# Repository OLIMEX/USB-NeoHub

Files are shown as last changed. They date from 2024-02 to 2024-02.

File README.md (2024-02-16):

# USB-NeoHub
USB 1.1 and USB 2.0 compliant hub compatible with RP2040 PICO USB and TinyUSB allowing keyboard, USB Flash and other peripherals to be used together

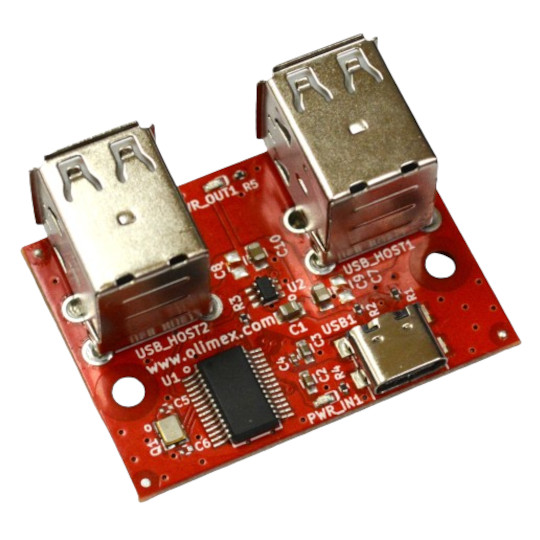
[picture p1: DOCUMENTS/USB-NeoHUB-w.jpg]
USB-NeoHUB-w


## Features

* USB 1.1 and USB 2.0 compatible
* USB-C input
* USB-A x4 output
* Input power status LED
* Output power status LED
* current protection
* Industrial grade temperature range: -40+85℃
* Dimensions 46x34 mm

## Licenses

* Hardware is released under CERN Open Hardware Licence Version 2 - Strongly Reciprocal, all silkscreen credits to Olimex should remain;
* Software is released under GPL3 Licensee
* Documentation is released under CC BY-SA 4.0

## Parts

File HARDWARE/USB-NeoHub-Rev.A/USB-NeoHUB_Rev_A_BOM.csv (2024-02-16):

Id | Designator | Footprint | Quantity | Designation | Supplier and ref
1 | U2 | SOT23-6 | 1 | CH217K(SOT23-6L)
2 | MH2,MH1 | Mounting_Hole_Drill-3.3mm_Clerance-7mm | 2 | Mounting_Hole_NPTH
3 | R5,R1,R2,R4 | R_0402_5MIL_DWS | 4 | 5.1k/1%/R0402
4 | R3 | R_0402_5MIL_DWS | 1 | 30.1k/1%/R0402
5 | C4 | C_0402_5MIL_DWS | 1 | 100nF/10V/10%/X7R/C0402
6 | FID4,FID3 | Fiducial1x3_Paste | 2 | Fiducial
7 | USB_HOST1,USB_HOST2 | USB_TWO_LEVEL | 2 | USBB1-FRWH-4A(USB-Ax2)
8 | U1 | SSOP28 | 1 | CH334S(SSOP-28)
9 | USB1 | USB2.0_TYPE-C(A40-00119-A52-12)_Paste | 1 | USB-C-16P-F(A40-00119-A52-12)
10 | FID2,FID1 | Fiducial1x3 | 2 | Fiducial
11 | PWR_OUT1,PWR_IN1 | LED_0603_KA | 2 | LED/GREEN/0603
12 | C7,C8 | C_0805_5MIL_DWS | 2 | NA(47uF/6.3V/20%/X5R/C0805)
13 | C3 | C_0603_5MIL_DWS | 1 | 10uF/6.3V/20%/X5R/C0603
14 | C5,C6 | C_0402_5MIL_DWS | 2 | NA(27pF/50V/5%/C0G/C0402)
15 | Q1 | TSX-3.2x2.5mm_GND(3) | 1 | Q12MHz/20pF/10ppm/4P/3.2x2.5mm
16 | C1,C9,C10 | C_0805_5MIL_DWS | 3 | 47uF/6.3V/20%/X5R/C0805
17 | C2 | C_0603_5MIL_DWS | 1 | 1uF/10V/20%/X5R/C0603
18 | Sign_RoHS_1 | Sign_RoHS_1 | 1 | Sign_RoHS_1
19 | Sign_RecycleBin_1 | Sign_RecycleBin_1 | 1 | Sign_RecycleBin_1
20 | Logo_OLIMEX_TB | Logo_OLIMEX_TB | 1 | Logo_OLIMEX_TB
21 | Sign_CE | CE_Sign | 1 | CE_Sign
22 | Sign_Antistatic | Sign_Antistatic | 1 | Sign_Antistatic
23 | Sign_PB-Free | Sign_PB-Free | 1 | Sign_PB-Free

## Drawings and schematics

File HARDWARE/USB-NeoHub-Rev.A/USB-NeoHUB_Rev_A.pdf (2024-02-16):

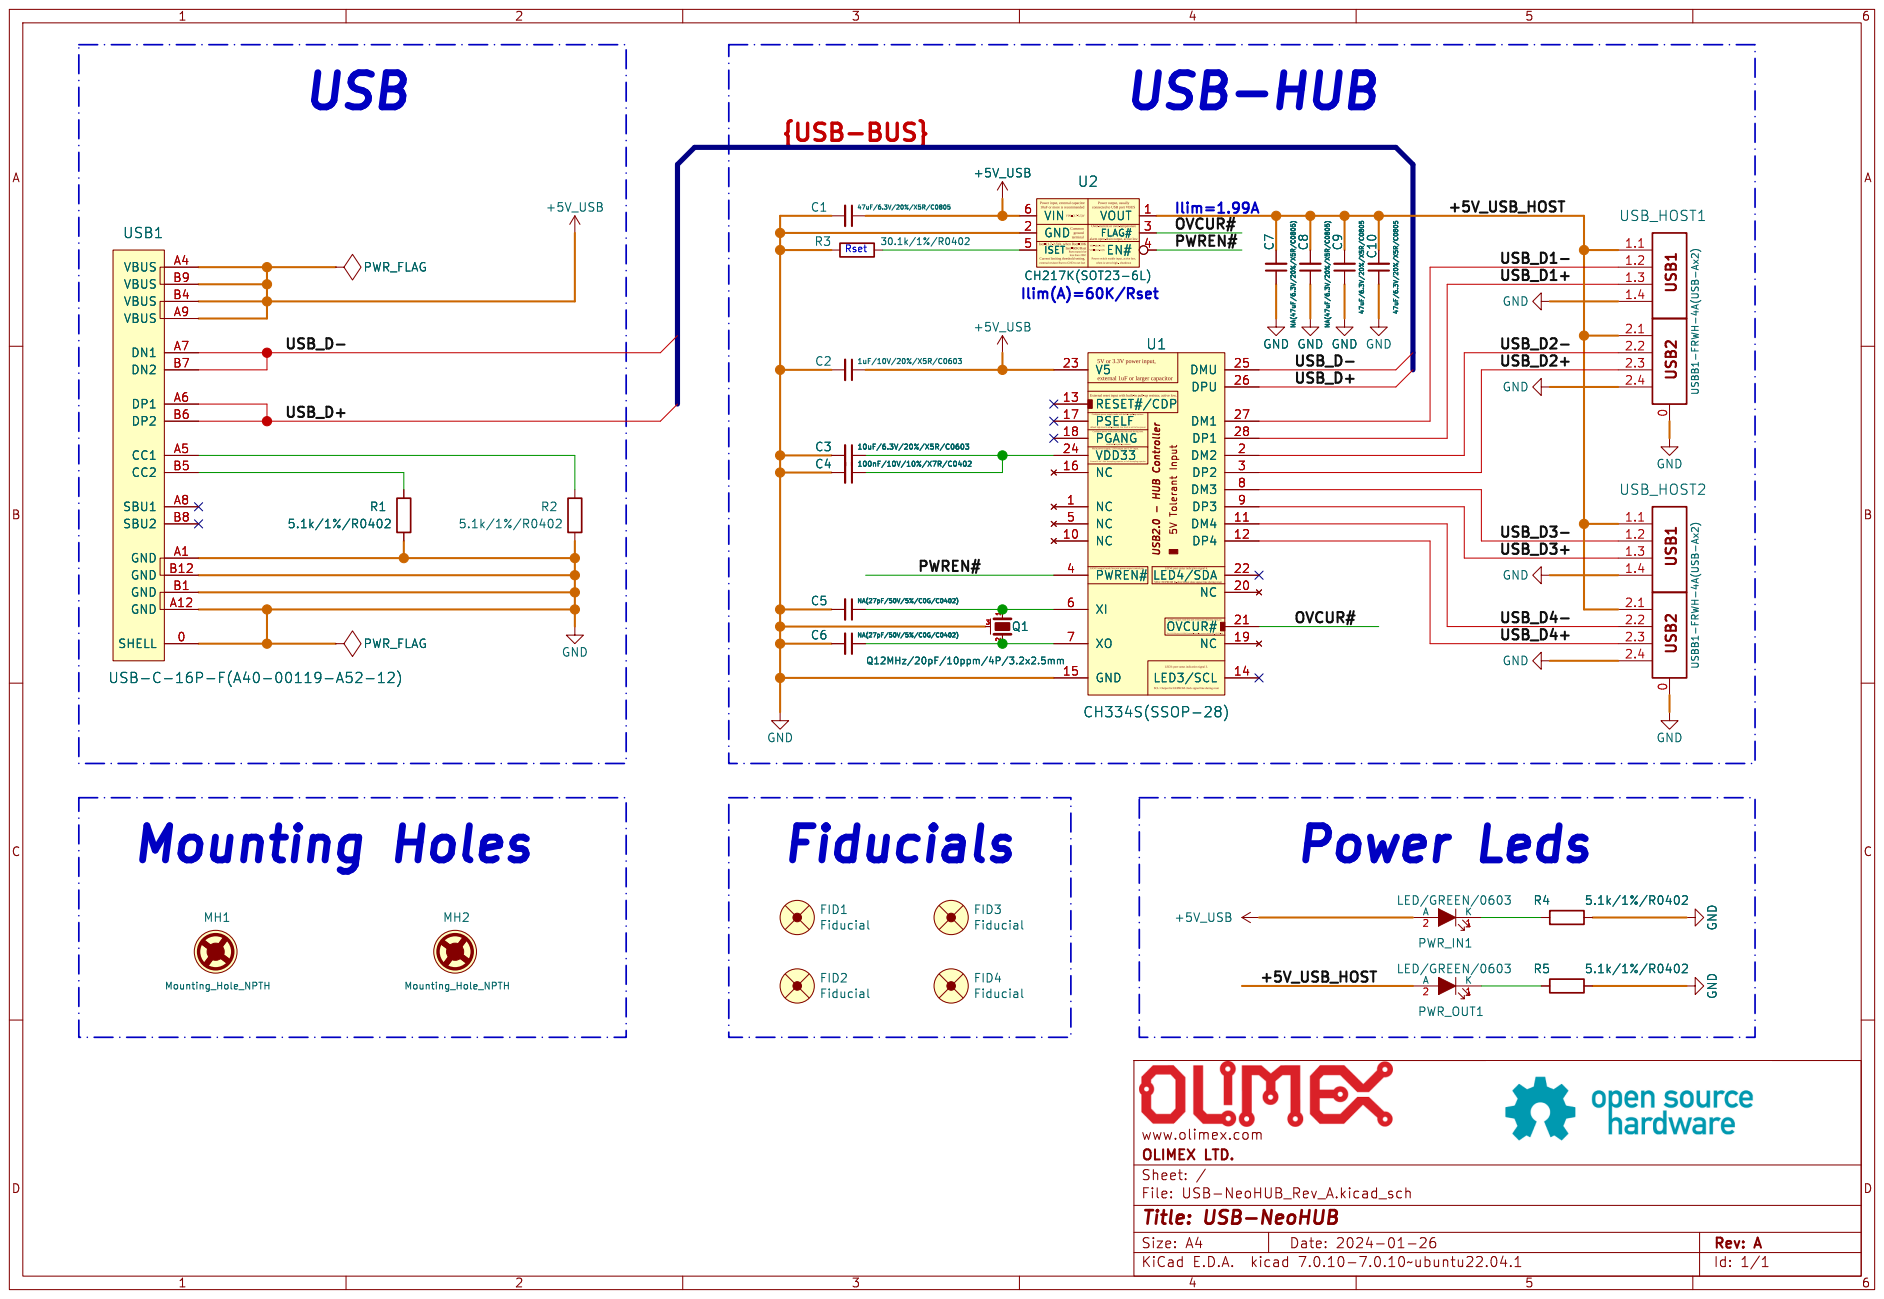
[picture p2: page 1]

lessthan22K! 10uFor moreis recommended | Over-currentor over-temperature Powerinput,externalcapacitor Poweroutput,usually Powerswitchenableinput,activelow, Rsetmustn'tbe VIL=(0.0-0.7)V VIN=(2.7-5.5)V whenis setto high - shutdown VOUT | 1 GND 2

terminal | connectedto USBportVBUS Currentlimiting thresholdsetting, externalresistorRsetto GND to setIset ground alarmopen-drainoutput,activelow Common VIH=(1.8-5.0)V

2.4 USB_HOST1USBB1-FRWH-4A(USB-Ax2) GND GND GND

Iset=(1.7-2.3)A,whenRset=30K Iset=60K/Rset

Configurepowerovercurrentprotectionmodeduringreset Configurepowersupplymodewith built-in pull-up resistor: defaulthigh level is self-powered,low level is setfor buspower External0.1uF+10uFdecouplingcapacitor,or 1uFdecouplingcapacitor external1uFor largercapacitor Externalresetinput with built-in pull-up resistor,activelow.

SCL:Outputfor EEPROMclock signalline duringreset SDA: EEPROMbi-directionaldatasignalline duringreset TheOVCUR#pin of CH334/5hasbuilt-in pull-up resistor(defaultOC_LEVEL=0).

Id: 1/1 Title: USB-NeoHUB

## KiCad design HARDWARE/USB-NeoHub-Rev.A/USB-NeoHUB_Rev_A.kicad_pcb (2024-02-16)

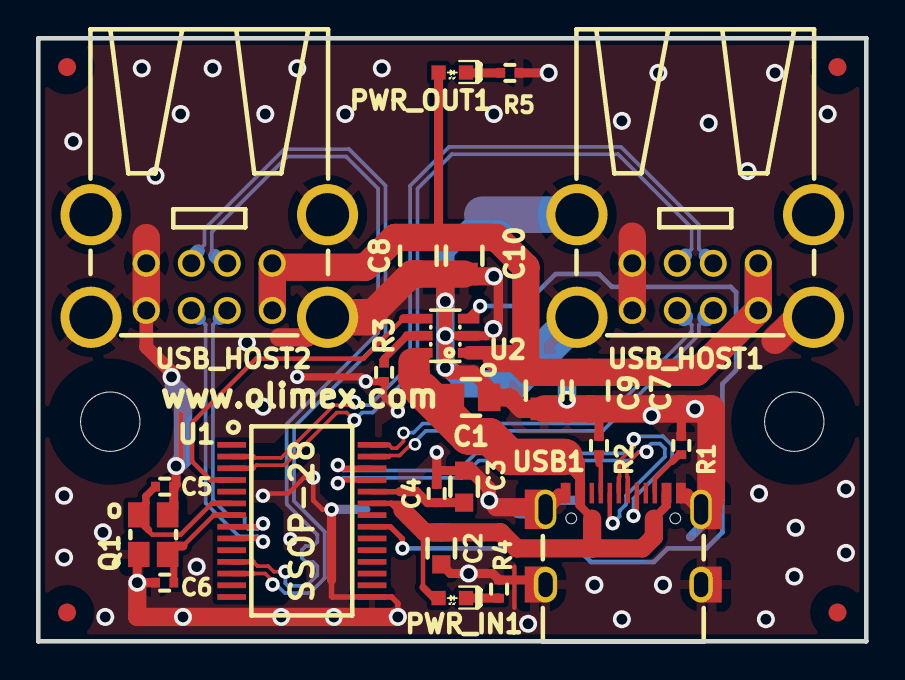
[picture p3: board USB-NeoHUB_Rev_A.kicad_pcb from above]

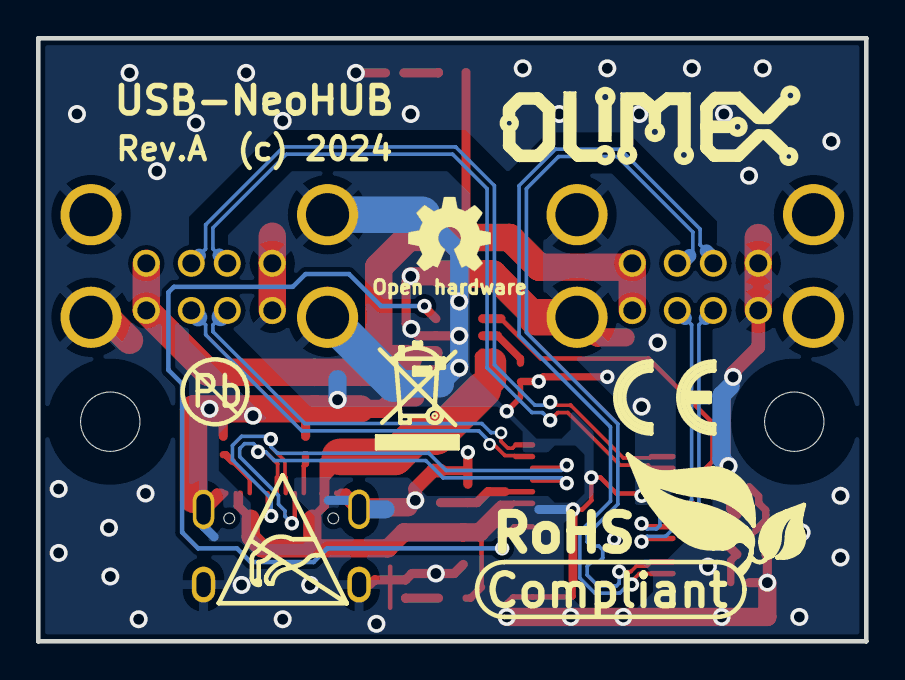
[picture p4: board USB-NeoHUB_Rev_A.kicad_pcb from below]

Board: 2 copper layers, 46.0 x 33.5 mm, 36 parts (7 on the bottom side), 23 nets.

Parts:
C1, C9, C10: 47uF/6.3V/20%/X5R/C0805; C_0805_5MIL_DWS
C2: 1uF/10V/20%/X5R/C0603; C_0603_5MIL_DWS
C3: 10uF/6.3V/20%/X5R/C0603; C_0603_5MIL_DWS
C4: 100nF/10V/10%/X7R/C0402; C_0402_5MIL_DWS
C5, C6: NA(27pF/50V/5%/C0G/C0402); C_0402_5MIL_DWS
C7, C8: NA(47uF/6.3V/20%/X5R/C0805); C_0805_5MIL_DWS
FID1, FID2: Fiducial; Fiducial1x3
FID3, FID4: Fiducial; Fiducial1x3_Paste
Logo_OLIMEX_TB: Logo_OLIMEX_TB
MH1, MH2: Mounting_Hole_NPTH; Mounting_Hole_Drill-3.3mm_Clerance-7mm
PWR_IN1: LED/GREEN/0603; LED_0603_KA
PWR_OUT1: LED/GREEN/0603; LED_0603_KA
Q1: Q12MHz/20pF/10ppm/4P/3.2x2.5mm; TSX-3.2x2.5mm_GND(3)
R1, R2, R4, R5: 5.1k/1%/R0402; R_0402_5MIL_DWS
R3: 30.1k/1%/R0402; R_0402_5MIL_DWS
Sign_Antistatic: Sign_Antistatic
Sign_CE: CE_Sign
Sign_OSHW_7.3x6.0mm: Sign_OSHW_7.3x6.0mm; Sign_OSHW_7.3x6.0mmn
Sign_PB-Free: Sign_PB-Free
Sign_RecycleBin_1: Sign_RecycleBin_1
Sign_RoHS_1: Sign_RoHS_1
U1: CH334S(SSOP-28); SSOP28
U2: CH217K(SOT23-6L); SOT23-6
USB1: USB-C-16P-F(A40-00119-A52-12); USB2.0_TYPE-C(A40-00119-A52-12)_Paste
USB_HOST1, USB_HOST2: USBB1-FRWH-4A(USB-Ax2); USB_TWO_LEVEL

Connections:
+5V_USB: C1.1, C2.1, PWR_IN1.2 (A), U1.23 (V5), U2.6 (VIN), USB1.A4 (VBUS), USB1.A9 (VBUS), USB1.B4 (VBUS), USB1.B9 (VBUS)
/+5V_USB_HOST: C7.2, C8.2, C9.2, C10.2, PWR_OUT1.2 (A), U2.1 (VOUT), USB_HOST1.1.1, USB_HOST1.2.1, USB_HOST2.1.1, USB_HOST2.2.1
/OVCUR#: U1.21 (OVCUR#), U2.3 (FLAG#)
/PWREN#: U1.4 (PWREN#), U2.4 (EN#)
/USB_D1+: U1.28 (DP1), USB_HOST1.1.3
/USB_D1-: U1.27 (DM1), USB_HOST1.1.2
/USB_D2+: U1.3 (DP2), USB_HOST1.2.3
/USB_D2-: U1.2 (DM2), USB_HOST1.2.2
/USB_D3+: U1.9 (DP3), USB_HOST2.1.3
/USB_D3-: U1.8 (DM3), USB_HOST2.1.2
/USB_D4+: U1.12 (DP4), USB_HOST2.2.3
/USB_D4-: U1.11 (DM4), USB_HOST2.2.2
/USB_D+: U1.26 (DPU), USB1.A6 (DP1), USB1.B6 (DP2)
/USB_D-: U1.25 (DMU), USB1.A7 (DN1), USB1.B7 (DN2)
GND: C1.2, C2.2, C3.2, C4.2, C5.2, C6.2, C7.1, C8.1, C9.1, C10.1, Q1.3 (case), R1.1, R2.1, R3.1, R4.2, R5.2, U1.15 (GND), U2.2 (GND), USB1.0 (SHELL), USB1.A1 (GND), USB1.A12 (GND), USB1.B1 (GND), USB1.B12 (GND), USB_HOST1.0, USB_HOST1.1.4, USB_HOST1.2.4, USB_HOST2.0, USB_HOST2.1.4, USB_HOST2.2.4
unnamed: PWR_IN1.1 (K), R4.1
unnamed: PWR_OUT1.1 (K), R5.1
unnamed: C3.1, C4.1, U1.24 (VDD33)
unnamed: C5.1, Q1.1, U1.6 (XI)
unnamed: C6.1, Q1.2, U1.7 (XO)
unnamed: R3.2, U2.5 (ISET)
unnamed: R2.2, USB1.A5 (CC1)
unnamed: R1.2, USB1.B5 (CC2)

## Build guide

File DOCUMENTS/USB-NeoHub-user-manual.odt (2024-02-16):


USB-NeoHub

User Manual

Rev.1.0 February 2024 olimex.com

# What is USB-NeoHub

USB-NeoHub (https://www.olimex.com/Products/USB-Modules/USB-NeoHub/open-source-hardware) is USB hub which is both USB 1.1 and USB 2.0 compatible. This is important as Neo6502 modern retro computer uses RP2040 to interface USB keyboards and USB Flash drives.

RP2040 USB interface is USB 1.1

For some weird reason not all USB hubs on the market support this standard which leads to incompatibilities. If you attach USB keyboard to Neo6502 it works, same is if you attach directly USB Flash. But if you attach USB keyboard through USB hub there is 50:50 chance that it may or may not work.

To save the customer frustration we decided to find USB hub chip set which guaranteed works with Neo6502.

This is how USB-NeoHub (https://www.olimex.com/Products/USB-Modules/USB-NeoHub/open-source-hardware) was made.

# USB-NeoHub features:

- USB 1.1 and USB 2.0 compliant
- USB-C device input
- USB-A x4 host outputs
- works with Neo6502, PC, OLinuXino, Raspberry Pi, RP2040-PICO and RP2040-PICO W
- Industrial grade -40+85C
- Dimensions are: 46 x 34

# Order codes for USB-NeoHub:

USB-NeoHub (https://www.olimex.com/Products/USB-Modules/USB-NeoHub/open-source-hardware) industrial grade -40+85C USB hub compatible with Neo6502

USB-CABLE-A-TO-C-1M (https://www.olimex.com/Products/Components/Cables/USB-CABLE-A-TO-C-1M/) USB-C cable

# HARDWARE

## USB-NeoHub layout:

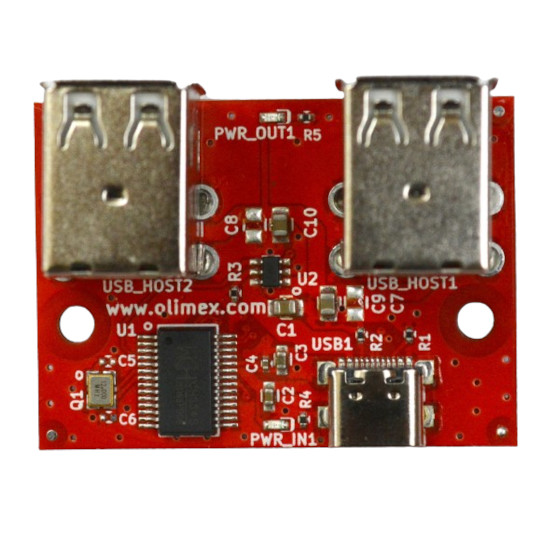
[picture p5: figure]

USB-C power indicator

USB-C device input

Dual USB-A host

USB host power indicator

Dual USB-A host

## USB-NeoHub schematics:

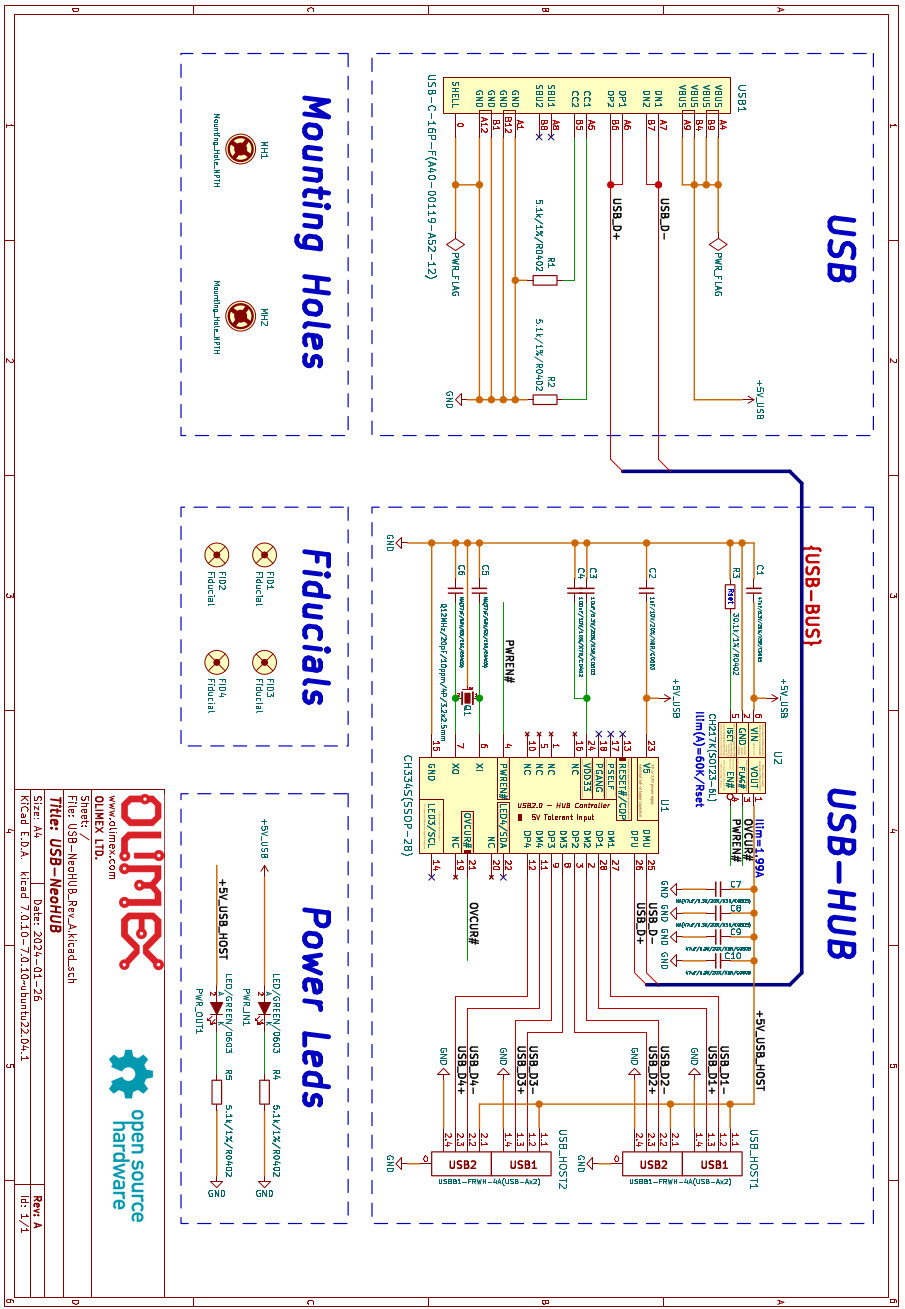
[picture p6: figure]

# Revision History

Revision 1.0 February 2024

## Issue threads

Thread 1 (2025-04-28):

power issue?

Mangerio, 2025-04-28:
Have tested the following system:
Tang Nano 20K + m0s Dock MCU and USB-NeoHub
with an Amiga 500 Keyboard driven by an Arduino Micro

It works some times and often it doesen't.
It works when the Power Out LED is on.
It works always with a wireless PC keyboard.
Does the Amiga KBD & Arduino Micro take too much power?
How is the current protection of the NeoHUB working?
What does the Power Out LED tell us exactly?

Mangerio, 2025-04-28:
The problem might be solved.
It probably was a weak powersupply.

Mangerio, 2025-04-28:
The NeoHUB might not get enough power from the m0s Dock?

Closed 2025-05-03.

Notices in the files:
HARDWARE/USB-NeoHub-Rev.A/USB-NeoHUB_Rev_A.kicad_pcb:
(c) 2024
